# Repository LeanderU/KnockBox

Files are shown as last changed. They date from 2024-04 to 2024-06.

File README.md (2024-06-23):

# KnockBox

Want to stay in contact with your friends, family, or partner over long distances? The KnockBox was created to foster a sense of proximity to them. Instead of physically knocking on their door, you can knock on your box, and theirs will imitate your physical knocking. Additionally, the pair of identical boxes can exchange short audio messages, similar to Walkie Talkies.  

## How it works:

This project focuses on an interactive device that communicates with identical boxes, independent of their locations. The boxes are connected via the Internet, allowing them to exchange knocking sounds and audio messages. A servo imitates the physical knocking coming from a user of another box, while an LED indicates if a new audio message has been received. The user interface is limited to only one button that's used for playing the received audio message, recording a message, and sending it.

## Repository Contents:

1. **Docs**: Contains the Product Brief and Project Requirements.
2. **Electrical**: Includes schematics and PCB design files.
3. **Software**: Contains testing of submodules.

*Please note that the code of the final KnockBox and documentation on the hardware development are still under revision and have not yet been included in this repository.*

https://github.com/LeanderU/KnockBox/assets/84909019/8b67ddaa-3543-461e-bd95-6ebf5e21cfc9

The video shown only demonstrates the ability to record and play the knocking sound. The capability of recording and replaying audio messages is not implemented yet.

KnockBox_Iso
KnockBox_Front
PXL_20240531_070939251 MP
Overview_with_descriptions

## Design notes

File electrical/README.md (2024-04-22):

After Assembly:

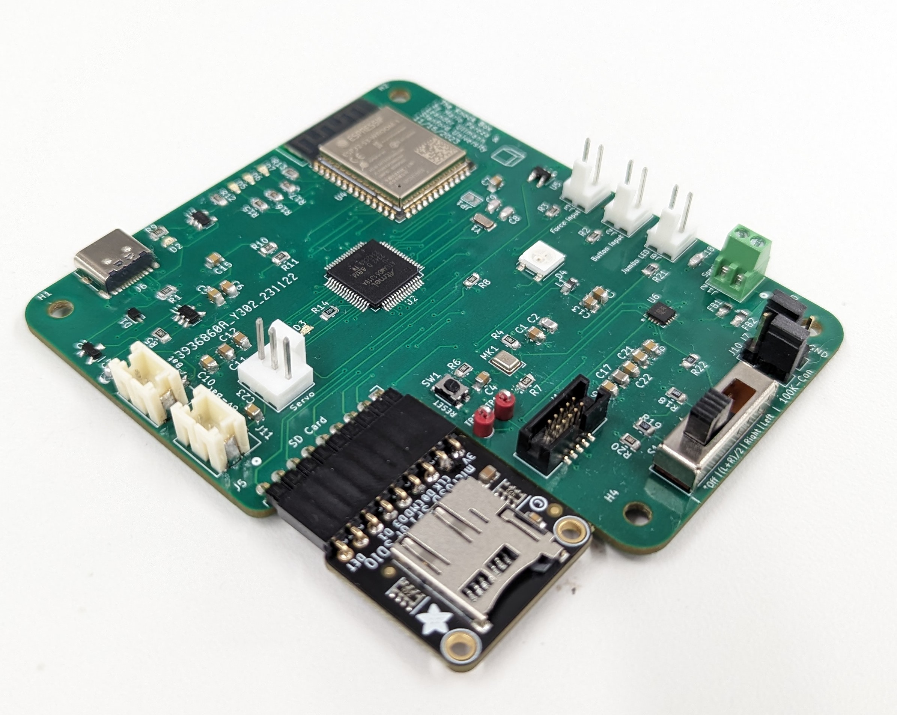
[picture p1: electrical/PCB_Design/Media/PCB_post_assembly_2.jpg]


Screenshot from KiCad before the files were sent to the Manufacturer:

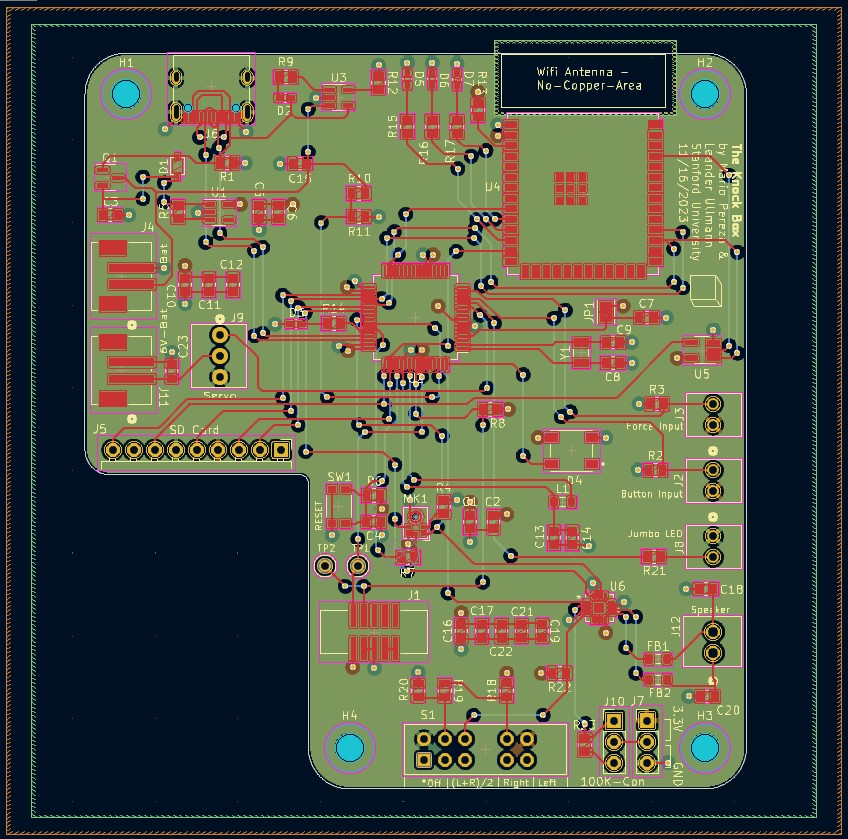
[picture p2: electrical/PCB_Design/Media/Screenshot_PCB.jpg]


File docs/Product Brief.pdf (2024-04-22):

Key features:
- Force sensor detects knocking on the box
- Servo imitates the knocking in the other box instantaneously
- Microphone used for short audio clips that are sent to second box
- Wifi modules enables communication via internet
- LED to signal a received audio clip
- Button to request to play the clip
- Speaker to output the audio clip received

Product Brief: Knock Box

Description

A way to feel more connected to those you care for by giving them a physical representation of your love. A pair of identical boxes communicating to each other. Both boxes send and receive knocks as well as audio messages.

Introduction
Want to stay in contact with your friends, family or partner over long distance?
Send a voice message and simply knock on their door…well…box to remind them that you’re there for them.
Of course, it also works the other way around, so wait until you hear a knocking sound or see the LED to indicate that you have received a new message.

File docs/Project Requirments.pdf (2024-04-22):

# Knock Box Requirements

The Knock Box comes in pairs. There must be two connected boxes for them to properly function. These boxes provide a way to feel more connected to those you care for by giving them a physical representation of your love.

# General Requirements

1. The Knock box shall be of cuboid shape
2. The walls of the cuboid shall be made out of a wooden material
3. Shall be able to record and send audio
4. An incoming message shall be signaled by an LED which turns off after the received audio message has been played
5. A speaker (power supply < 12V) shall play the received audio message when a button has been pressed

# User Interfaces

Audio Recording
- There shall be a button to hold when the user wants to record an audio message.
- A microphone shall record a voice message for up to 10 seconds.

Haptics
- The user will be able to knock on their box to trigger a simulated knock on the corresponding paired box.
- The knocking shall be detected by a force sensor
- The knocking sound on the corresponding box shall be accomplished by a hammer-like object that is attached to a servo motor.

# Communications

### WiFi

1. The Knock Box shall be capable of functioning as a WiFi client on 802.11 b/g/n wireless networks to communicate with another Knock Box

# Power

1. The Knock Box shall be powered by an internal rechargeable battery.
2. The Knock Box shall be able to be mains powered via an AC power adapter.

3. The AC power adapter shall be capable of providing power using mains voltages from 100 VAC to 240 VAC ± 10% with line frequencies of 50 to 60 Hz.
4. The Knock Box shall be able to run for over 8 hours when powered from its fully charged internal Li-Ion batteries.
5. The internal Li-Ion battery shall be able to be charged via the USB port.
6. The internal Li-Ion battery shall be able to be charged via the AC power adapter port.

# Environmental

1. Ingress protection for the Kock Box shall be IP 41 per ANSI/IEC 60529
2. The Knock Box shall operate over a temperature range of 0 °C to +40 °C with the internal Li-Ion battery installed.
3. The Knock Box shall operate over a temperature range of 0 °C to +50 °C without the internal Li-Ion battery installed.
4. The Knock Box shall sustain no damage while stored or placed in a non-operating condition over a temperature range of -20 °C to +60 °C with no internal Li-Ion battery installed.
5. The Knock Box shall be operable under the following temperature / humidity conditions:
a. 10 °C to 30 °C - up to 95% relative humidity, non-condensing
b. 30 °C to 40 °C - up to 75% relative humidity, non-condensing
c. 40 °C to 50 °C - up to 45% relative humidity, non-condensing
6. Under non-operating conditions, the Knock Box shall sustain no damage from 0 % to 98% relative humidity, non-condensing over the temperature range from -20 °C to +60 °C.
7. The Knock Box shall be operable from 400 m below mean sea level to 3,000 m above mean sea level.
8. A non-operational Knock Box shall sustain no damage from exposure to altitudes from 500 m below mean sea level to 12,000 m above mean sea level regardless of exposure duration.
9. The Knock Box shall be capable of operating under conditions of sinusoidal vibration of 3 g maximum according to MIL-PRF-28800F, Class 2.
10. The Knock Box shall be capable of operating under conditions of 30 g shock according to MIL-PRF-28800F, Class 2.
11. The Knock Box shall suffer no damage when dropped from a height of 10 cm per MIL-STD-810H

# Regulatory

1. The Knock Box shall meet or exceed the requirements of electromagnetic compatibility standards EN IEC 61326-1:2021 and EN IEC 61326-2:2021 for emission and immunity.

2. The Knock Box shall meet or exceed the requirements of UL61010-1:2023, CAN/CSA C22.2 No. 61010.1-12, EN 61010-1:2010.
3. The Knock Box shall meet or exceed the requirements of IEC / EN 61000-4-2 testing.

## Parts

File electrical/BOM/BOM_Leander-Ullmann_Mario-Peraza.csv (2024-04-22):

BOM - Knock Box
Note: Quantities in red refer to two boxes (one for Mario and one for Leander) plus some reasonable buffer.
# | Sourced | Placed | References | Value | Footprint | MFR | MFR Part Number | Supplier 1 | Supplier 1 Part Number | URL | $ per Unit | Quantity single Box | $ per categorie per box | Quantity to Order (two Boxes plus buffer) | $ per categorie for both boxes plus buffer
1 |  |  | C3, C5, C10, C15, C16, C19, C21, C22, C23 | 10uF | G-21_MUR | Murata Electronics | GRM21BR61C106KE15K | DigiKey | 490-6473-1-ND |  | $0.18 | 9 | $1.62 | 22 | $3.96
2 |  |  | C1, C4, C6, C7, C11, C12, C13, C14 | 1uF | G-21_MUR | Murata Electronics | GRM21BR71C105KA01L | DigiKey | 490-1691-1-ND |  | $0.21 | 8 | $1.68 | 20 | $4.20
3 |  |  | C2, C18, C20 | 220pF | G-21_MUR | Murata Electronics | GRM21A5C2E221JW01D | DigiKey | 490-13371-1-ND |  | $0.25 | 3 | $0.75 | 10 | $2.50
4 |  |  | C8, C9 | 22pF | G-21_MUR | Murata Electronics | GRM21A5C2D220JW01D | DigiKey | 490-14650-1-ND |  | $0.25 | 2 | $0.50 | 8 | $2.00
5 |  |  | C17 | 0.1uF | G-21_MUR | Murata Electronics | GRM21B7U1A104JA01L | DigiKey | 490-11592-1-ND |  | $0.32 | 1 | $0.32 | 6 | $1.92
6 |  |  | R2, R3, R4, R5, R6, R8, R12, R13 | 10K | STA_RMCF0805_STP | Stackpole Electronics Inc | RMCF0805FT10K0 | DigiKey | RMCF0805FT10K0CT-ND |  | $0.10 | 8 | $0.80 | 20 | $2.00
7 |  |  | R9, R15, R16, R17, R20 | 1K | STA_RMCF0805_STP | Stackpole Electronics Inc | RMCF0805FT1K00 | DigiKey | RMCF0805FT1K00CT-ND |  | $0.10 | 5 | $0.50 | 14 | $1.40
8 |  |  | R1, R10, R11, R23 | 100K | STA_RMCF0805_STP | Stackpole Electronics Inc | RMCF0805FT100K | DigiKey | RMCF0805FT100KCT-ND |  | $0.10 | 4 | $0.40 | 12 | $1.20
9 |  |  | R14, R19, R21 | 2.2K | STA_RMCF0805_STP | Stackpole Electronics Inc | RMCF0805FT2K20 | DigiKey | RMCF0805FT2K20CT-ND |  | $0.10 | 3 | $0.30 | 10 | $1.00
10 |  |  | R7 | 68 | STA_RMCF0805_STP | Stackpole Electronics Inc | RMCF0805JT68R0 | DigiKey | RMCF0805JT68R0CT-ND |  | $0.10 | 1 | $0.10 | 4 | $0.40
11 |  |  | R18 | 6.8K | STA_RMCF0805_STP | Stackpole Electronics Inc | RMCF0805FT6K80 | DigiKey | RMCF0805FT6K80CT-ND |  | $0.10 | 1 | $0.10 | 4 | $0.40
12 |  |  | R22 | 1M | STA_RMCF0805_STP | Stackpole Electronics Inc | RMCF0805JT1M00 | DigiKey | RMCF0805JT1M00CT-ND |  | $0.10 | 1 | $0.10 | 4 | $0.40
13 |  |  | L1 | 10uH | L_0805_2012Metric | Bourns Inc. | CV201210-100K | DigiKey | CV201210-100KCT-ND |  | $0.10 | 1 | $0.10 | 4 | $0.40
14 |  |  | D3, D6 | RED LED | LED_LTST-C191KRKT_LTO | Lite-On Inc. | LTST-C191KRKT | DigiKey | 160-1447-1-ND |  | $0.25 | 2 | $0.50 | 6 | $1.50
15 |  |  | D1 | D_Schottky | SDO_RB550VM-30TE-17_ROM | Rohm Semiconductor | RB550VM-30TE-17 | DigiKey | 846-RB550VM-30TE-17CT-ND |  | $0.38 | 1 | $0.38 | 4 | $1.52
16 |  |  | D2 | ORANGE LED | LED_LTST-C191KRKT_LTO | Lite-On Inc. | LTST-C191KFKT | DigiKey | 160-1445-1-ND |  | $0.23 | 1 | $0.23 | 4 | $0.92
17 |  |  | D4 | NeoPixel_THT | LED_1655 | Adafruit Industries LLC | 1655 | DigiKey | 1528-1104-ND |  | $4.50 | 1 | $4.50 | 4 | $18.00
18 |  |  | D5 | BLUE LED | LED_LTST-C191KRKT_LTO | Lite-On Inc. | LTST-C191TBKT | DigiKey | 160-1647-1-ND |  | $0.34 | 1 | $0.34 | 4 | $1.36
19 |  |  | D7 | GREEN LED | LED_LTST-C191KRKT_LTO | Lite-On Inc. | LTST-C191KGKT | DigiKey | 160-1446-1-ND |  | $0.25 | 1 | $0.25 | 4 | $1.00
20 |  |  | U1 | AP2112K-3.3 | SOT-23-5 | Diodes Incorporated | AP2112K-3.3TRG1 | DigiKey | AP2112K-3.3TRG1DICT-ND |  | $0.35 | 1 | $0.35 | 3 | $1.05
21 |  |  | U2 | ATSAMD51J19A-A | TQFP-64_10x10mm_P0.5mm | Microchip Technology | ATSAMD51J19A-AUT | DigiKey | ATSAMD51J19A-AUTCT-ND |  | $5.68 | 1 | $5.68 | 3 | $17.04
22 |  |  | U3 | MCP73831-2-OT | SOT-23-5 | Microchip Technology | MCP73831T-2ACI/OT | DigiKey | MCP73831T-2ACI/OTCT-ND |  | $0.76 | 1 | $0.76 | 3 | $2.28
23 |  |  | U4 | ESP32-S3-WROOM-1-N16R8 | ESP32-S3-WROOM-1U_EXP | Espressif Systems | ESP32-S3-WROOM-1-N16R8 | DigiKey | 1965-ESP32-S3-WROOM-1-N16R8CT-ND |  | $2.95 | 1 | $2.95 | 3 | $8.85
24 |  |  | U5 | 74AHC1G125 | USB_C_Receptacle_XKB_U262-16XN-4BVC11 | Texas Instruments | SN74AHC1G125DBVR | DigiKey | 296-8744-1-ND |  | $0.37 | 1 | $0.37 | 3 | $1.11
25 |  |  | U6 | MAX98357AETE+T | 21-0136I_T1633-4_MXM | Analog Devices Inc./Maxim Integrated | MAX98357AETE+T | DigiKey | MAX98357AETE+TCT-ND |  | $2.89 | 1 | $2.89 | 3 | $8.67
26 |  |  | Y1 | Crystal | Crystal_SMD_MicroCrystal_CC7V-T1A-2Pin_3.2x1.5mm | ECS Inc. | ECS-.327-12.5-34B-TR | DigiKey | XC1617CT-ND |  | $0.44 | 1 | $0.44 | 4 | $1.76
27 |  |  | SW1 | KMR231NG LFS | IC4_KMR231NGLFS_CNK |  | KMR231NG LFS | DigiKey | CKN10246CT-ND |  | $0.64 | 1 | $0.64 | 4 | $2.56
28 |  |  | H1, H2, H3, H4 | MountingHole | MountingHole_3.2mm_M3_ISO7380 |  |  |  |  |  |  | 4 | $- | 0 | $-
29 |  |  | FB1, FB2 | FerriteBead | L_0805_2012Metric | Laird-Signal Integrity Products | HI0805Q310R-10 | DigiKey | 240-2394-1-ND |  | $0.20 | 2 | $0.40 | 6 | $1.20
30 |  |  | TP1, TP2 | TestPoint | KEYSTONE_5000 | Keystone Electronics | 5000 | DigiKey | 36-5000-ND |  | $0.38 | 2 | $0.76 | 6 | $2.28
31 |  |  | JP1 | ~ | SolderJumper-2_P1.3mm_Open_TrianglePad1.0x1.5mm |  |  |  |  |  |  | 1 | $- | 0 | $-
32 |  |  | MK1 | SPH0645LM4H | Knowles_SPH0645LM4H-6_3.5x2.65mm | Knowles | SPH0645LM4H-B | DigiKey | 423-SPH0645LM4H-BCT-ND |  | $2.74 | 1 | $2.74 | 4 | $10.96
33 |  |  | Q1 | BSS84 | SOT-23 | Diodes Incorporated | BSS84-7-F | DigiKey | BSS84-FDICT-ND |  | $0.24 | 1 | $0.24 | 3 | $0.72
34 |  |  | S1 | SS-24E06-TG_5__P_ | SW_SS-24E06-TG_5__P_ | C&K | SS-24E06-TG 5 (P) | DigiKey | CKN10394-ND |  | $1.15 | 1 | $1.15 | 3 | $3.45
35 |  |  | J2, J3, J8 | Molex2 | CONN_22232021_MOL | Molex | 22232021 | DigiKey | 900-0022232021-ND |  | $0.21 | 3 | $0.63 | 8 | $1.68
36 |  |  | J4, J11 | B2B-PH-SM4-TB | CONN_B2B-PH-SM4-TBLFSN_JST | JST Sales America Inc. | B2B-PH-SM4-TB | DigiKey | 455-B2B-PH-SM4-TBCT-ND |  | $0.55 | 2 | $1.10 | 6 | $3.30
37 |  |  | J7, J10 | 61300311121 | PinHeader_1x03_P2.54mm_Vertical | Würth Elektronik | 61300311121 | DigiKey | 732-5316-ND |  | $0.13 | 2 | $0.26 | 6 | $0.78
38 |  |  | J1 | 3221-10-0300-00 | CONN10_3221-10-0300-00_CNC | CNC Tech | 3221-10-0300-00 | DigiKey | 1175-1735-ND |  | $0.76 | 1 | $0.76 | 3 | $2.28
39 |  |  | J5 | 61300911021 | PinHeader_1x09_P2.54mm_Horizontal | Würth Elektronik | 61300911021 | DigiKey | 732-5342-ND |  | $0.88 | 1 | $0.88 | 3 | $2.64
40 |  |  | J6 | USB_C_Receptacle_USB2.0 | USB_C_Receptacle_XKB_U262-16XN-4BVC11 | XKB Connectivity | U262-161N-4BVC11 | LCSC ELECTRONICS | C319148 |  | $0.40 | 1 | $0.40 | 3 | $1.20
41 |  |  | J9 | Molex3 | CONN3_22232031_MOL | Molex | 22232031 | DigiKey | WM4201-ND |  | $0.27 | 1 | $0.27 | 3 | $0.81
42 |  |  | J12 | OSTVN02A150 | CONN_OSTVN02A150_OST | On Shore Technology Inc. | OSTVN02A150 | DigiKey | ED10561-ND |  | $1.08 | 1 | $1.08 | 3 | $3.24
43 |  |  | not part of PCB | Force Sensor |  | Adafruit Industries LLC | 1075 | Adafruit Industries LLC | 1075 |  | $5.95 | 1 | $5.95 | 2 | $11.90
44 |  |  | not part of PCB | Jumbo LED Green |  | Kingbright | WP813GD | DigiKey | 754-1898-ND |  | $0.43 | 1 | $0.43 | 2 | $0.86
45 |  |  | not part of PCB | Jumbo LED Red |  | Kingbright | WP813SURDK | DigiKey | 754-WP813SURDK-ND |  | $0.62 | 0 | $- | 2 | $1.24
46 |  |  | not part of PCB | 6V Servo Motor |  | Parallax Inc. | 900-00005 | DigiKey | 900-00005-ND |  | $15.87 | 1 | $15.87 | 2 | $31.74
47 |  |  | not part of PCB | 16mm Flush Button |  | - | - | Ebay | 1.31657E+11 | https://www.ebay.com/itm/131657180740 | $5.99 | 1 | $5.99 | 2 | $11.98
48 |  |  | not part of PCB | SD-Card-Module |  | Adafruit Industries LLC | 4682 | DigiKey | 1528-4682-ND |  | $3.50 | 1 | $3.50 | 3 | $10.50
49 |  |  | not part of PCB | Jumper Pin Shunts |  | Sullins Connector Solutions | STC02SYAN | DigiKey | S9000-ND |  | $0.10 | 2 | $0.20 | 6 | $0.60
50 |  |  | not part of PCB | Female Socket Angled |  | Sullins Connector Solutions | PPPC091LGBN-RC | DigiKey | S5484-ND |  | $0.77 | 1 | $0.77 | 2 | $1.54
51 |  |  | not part of PCB | Male Header Angled |  | W�rth Elektronik | 61300911021 | DigiKey | 732-5342-ND |  | $0.88 | 1 | $0.88 | 2 | $1.76
52 |  |  | not part of PCB | Molex Crimp Housing 2 Pins |  | Molex | 22013027 | DigiKey | 900-0022013027-ND |  | $0.16 | 3 | $0.48 | 10 | $1.60
53 |  |  | not part of PCB | Molex Crimp Housing 3 Pins |  | Molex | 22013037 | DigiKey | 900-0022013037-ND |  | $0.19 | 1 | $0.19 | 3 | $0.57
54 |  |  | not part of PCB | Crimp Terminals |  | Molex | 8650804 | DigiKey | WM2756CT-ND |  | $0.10 | 9 | $0.90 | 30 | $3.00
55 |  |  | not part of PCB | Battery Pack |  | Adafruit Industries LLC | 3859 | DigiKey | 1528-2707-ND |  | $2.95 | 1 | $2.95 | 2 | $5.90
56 |  |  | not part of PCB | AA Batteries |  | Panasonic - BSG | LR6XWA/BXU | DigiKey | 11-LR6XWA/BXU-ND |  | $0.44 | 4 | $1.76 | 8 | $3.52
57 |  |  | not part of PCB | Lithion Battery 3.7V |  | SparkFun Electronics | PRT-13855 | DigiKey | 1568-1686-ND |  | $13.95 | 1 | $13.95 | 2 | $27.90
 |  |  |  | SD Card |  |  |  |  |  |  |  |  | $92.04 |  | $238.55
 |  |  |  | Speaker

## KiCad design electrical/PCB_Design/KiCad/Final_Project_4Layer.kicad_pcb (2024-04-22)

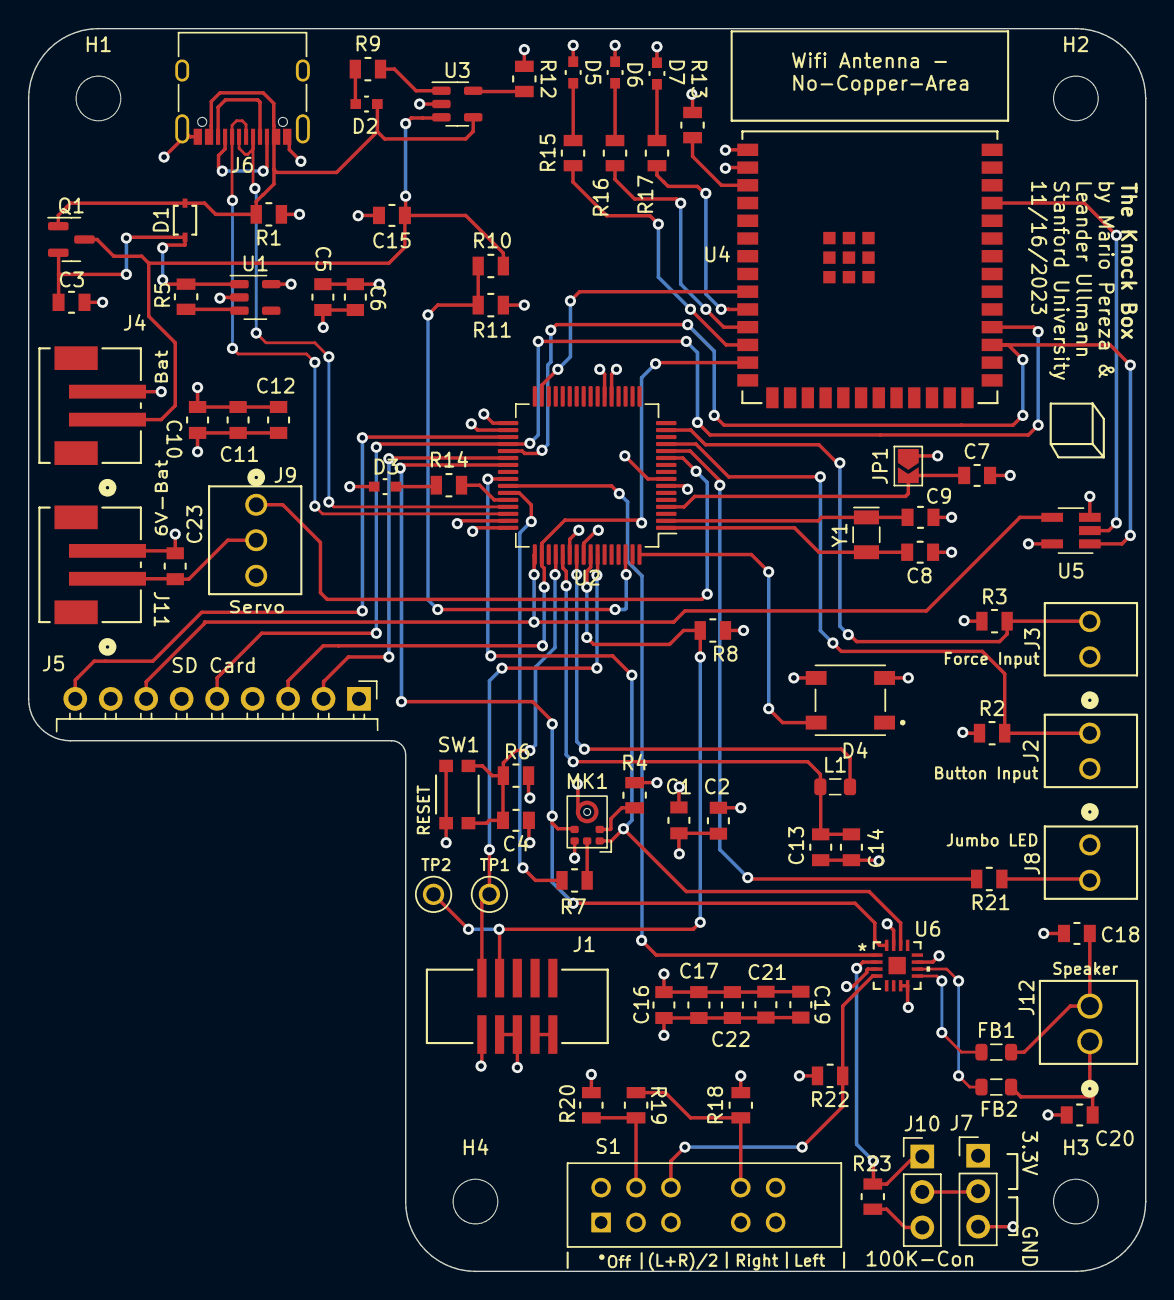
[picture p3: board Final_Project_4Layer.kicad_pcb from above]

Board: 4 copper layers, 80.0 x 89.0 mm, 86 parts (0 on the bottom side), 60 nets.

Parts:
C1, C4, C6, C7, C11, C12, C13, C14: 1uF; G-21_MUR
C2, C18, C20: 220pF; G-21_MUR
C3, C5, C10, C15, C16, C19, C21, C22, C23: 10uF; G-21_MUR
C8, C9: 22pF; G-21_MUR
C17: 0.1uF; G-21_MUR
D1: D_Schottky; SDO_RB550VM-30TE-17_ROM
D2: ORANGE LED; LED_LTST-C191KRKT_LTO
D3, D6: RED LED; LED_LTST-C191KRKT_LTO
D4: NeoPixel_THT; LED_1655
D5: BLUE LED; LED_LTST-C191KRKT_LTO
D7: GREEN LED; LED_LTST-C191KRKT_LTO
FB1, FB2: FerriteBead; L_0805_2012Metric
H1, H2, H3, H4: MountingHole; MountingHole_3.2mm_M3_ISO7380
J1: 3221-10-0300-00; CONN10_3221-10-0300-00_CNC
J2, J3, J8: Molex2; CONN_22232021_MOL
J4, J11: B2B-PH-SM4-TB; CONN_B2B-PH-SM4-TBLFSN_JST
J5: 61300911021; PinHeader_1x09_P2.54mm_Horizontal
J6: USB_C_Receptacle_USB2.0; USB_C_Receptacle_XKB_U262-16XN-4BVC11
J7, J10: 61300311121; PinHeader_1x03_P2.54mm_Vertical
J9: Molex3; CONN3_22232031_MOL
J12: OSTVN02A150; CONN_OSTVN02A150_OST
JP1: SolderJumper-2_P1.3mm_Open_TrianglePad1.0x1.5mm
L1: 10uH; L_0805_2012Metric
MK1: SPH0645LM4H; Knowles_SPH0645LM4H-6_3.5x2.65mm
Q1: BSS84; SOT-23
R1, R10, R11, R23: 100K; STA_RMCF0805_STP
R2, R3, R4, R5, R6, R8, R12, R13: 10K; STA_RMCF0805_STP
R7: 68; STA_RMCF0805_STP
R9, R15, R16, R17, R20: 1K; STA_RMCF0805_STP
R14, R19, R21: 2.2K; STA_RMCF0805_STP
R18: 6.8K; STA_RMCF0805_STP
R22: 1M; STA_RMCF0805_STP
S1: SS-24E06-TG_5__P_; SW_SS-24E06-TG_5__P_
SW1: KMR231NG LFS; IC4_KMR231NGLFS_CNK
TP1, TP2: TestPoint; KEYSTONE_5000
U1: AP2112K-3.3; SOT-23-5
U2: ATSAMD51J19A-A; TQFP-64_10x10mm_P0.5mm
U3: MCP73831-2-OT; SOT-23-5
U4: ESP32-S3-WROOM-1-N16R8; ESP32­S3­WROOM­1U_EXP
U5: 74AHC1G125; SOT-23-5_HandSoldering
U6: MAX98357AETE+T; 21-0136I_T1633-4_MXM
Y1: Crystal; Crystal_SMD_MicroCrystal_CC7V-T1A-2Pin_3.2x1.5mm

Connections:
+3.3V: C1.1, C2.1, C5.1, C6.1, C10.1, C11.1, C12.1, C16.2, C17.2, C19.1, C21.1, C22.1, D4.3 (VDD), J1.6, J2.1, J3.1, J5.4, J7.1, JP1.1 (A), MK1.5 (VDD), R6.2, R8.1, R13.1, R18.2, R22.2, S1.6, U1.5 (VOUT), U2.8 (VDDANA), U2.21 (VDDIOB), U2.34 (VDDIO), U2.48 (VDDIO), U2.56 (VDDIO), U4.2 (VDD), U5.5 (VCC), U6.7 (VDD), U6.8 (VDD)
+6V: C23.1, J9.2, J11.1
+BATT: C15.2, J4.1, Q1.3 (D), R10.2, U3.3 (V_{BAT})
/AMPL_GAIN_SEL: J10.1, R23.1, U6.2 (GAIN_SLOT)
/AREF: C7.1, JP1.2 (B), U2.4 (PA03)
/Button_Signal: J2.2, R2.2, U2.13 (PA04)
/CS_Card: J5.2, U2.38 (PA19)
/CS_Wifi: U2.37 (PA18), U4.29 (IO5), U5.1
/Card_Detect: J5.9, U2.35 (PA16)
/ESP_Busy: U2.31 (PA14), U4.9 (IO33)
/Force_Signal: J3.2, R3.2, U2.15 (PA06)
/I2S_BCLK: MK1.4 (BCLK), U2.39 (PB16), U6.16 (BCLK)
/I2S_DIN: U2.42 (PA21), U6.1 (DIN)
/I2S_DOUT: R7.1, U2.43 (PA22)
/I2S_LRCLK: MK1.1 (WS), U2.41 (PA20), U6.14 (LRCLK)
/MISO: J5.7, U2.49 (PB22), U5.4
/MISO_ESP: U4.37 (IO23), U5.2
/MOSI: J5.3, U2.50 (PB23), U4.13 (IO14)
/SCK: J5.5, U2.36 (PA17), U4.30 (IO18)
/SD_MODE: R22.1, S1.8, U6.4 (*SD_MODE)
/SWCLK: J1.2, R8.2, TP2.TP (1), U2.57 (PA30)
/SWDIO: J1.1, TP1.TP (1), U2.58 (PA31)
/VO+: FB2.1, U6.10 (OUTN)
/VO-: FB1.1, U6.9 (OUTP)
/V_DIV: R10.1, R11.2, U2.62 (PB01)
D8_NEOPIX: D4.4 (DIN), U2.64 (PB03)
D+: J6.A6 (D+), J6.B6 (D+), U2.46 (PA25)
D-: J6.A7 (D-), J6.B7 (D-), U2.45 (PA24)
ESP_BLUE: R15.1, U4.12 (IO27)
ESP_GREEN: R17.1, U4.10 (IO25)
ESP_RED: R16.1, U4.11 (IO26)
GND: C1.2, C2.2, C3.2, C4.2, C5.2, C6.2, C7.2, C8.1, C9.1, C10.2, C11.2, C12.2, C13.1, C14.1, C15.1, C16.1, C17.1, C18.2, C19.2, C20.2, C21.2, C22.2, C23.2, D3.1 (K), D4.2 (GND), D5.1 (K), D6.1 (K), D7.1 (K), J1.7, J1.8, J4.2, J5.6, J6.A1 (GND), J6.A12 (GND), J6.B1 (GND), J6.B12 (GND), J6.S1 (SHIELD), J7.3, J8.2, J9.3, J11.2, MK1.3 (GND), R1.1, R2.1, R3.1, R4.1, R11.1, R12.1, R20.2, S1.10, SW1.1, SW1.3, U1.2 (GND), U2.7 (GNDANA), U2.22 (GND), U2.33 (GND), U2.47 (GND), U2.54 (GND), U3.2 (V_{SS}), U4.1 (GND), U5.3 (GND), U6.3 (GND), U6.11 (GND), U6.15 (GND)
JUMBO_LED: R21.1, U2.12 (PB09)
unnamed: C18.1, FB1.2, J12.2
unnamed: C20.1, FB2.2, J12.1
unnamed: C3.1, D1.1 (K), Q1.2 (S), R5.2, U1.1 (VIN)
unnamed: D2.1 (K), R9.2
unnamed: D3.2 (A), R14.2
unnamed: D5.2 (A), R15.2
unnamed: D6.2 (A), R16.2
unnamed: D7.2 (A), R17.2
unnamed: J8.1, R21.2
unnamed: J7.2, J10.2
unnamed: J10.3, R23.2
unnamed: MK1.6 (DATA), R7.2
unnamed: MK1.2 (SEL), R4.2
unnamed: R18.1, R19.1, S1.7
unnamed: R19.2, R20.1, S1.9
unnamed: R5.1, U1.3 (EN)
unnamed: C8.2, U2.1 (PA00), Y1.2
unnamed: C9.2, U2.2 (PA01), Y1.1
unnamed: C13.2, C14.2, L1.1, U2.53 (VDDCORE)
unnamed: L1.2, U2.55 (VSW)
unnamed: R12.2, U3.5 (PROG)
unnamed: R9.1, U3.1 (STAT)
unnamed: R13.2, U4.3 (EN)
PWM_Servo: J9.1, U2.11 (PB08)
RED_LED: R14.1, U2.44 (PA23)
RESET: C4.1, R6.1, SW1.2, SW1.4, U2.52 (~RESET)
VBUS: D1.2 (A), D2.2 (A), J6.A4 (VBUS), J6.A9 (VBUS), J6.B4 (VBUS), J6.B9 (VBUS), Q1.1 (G), R1.2, U3.4 (V_{DD})

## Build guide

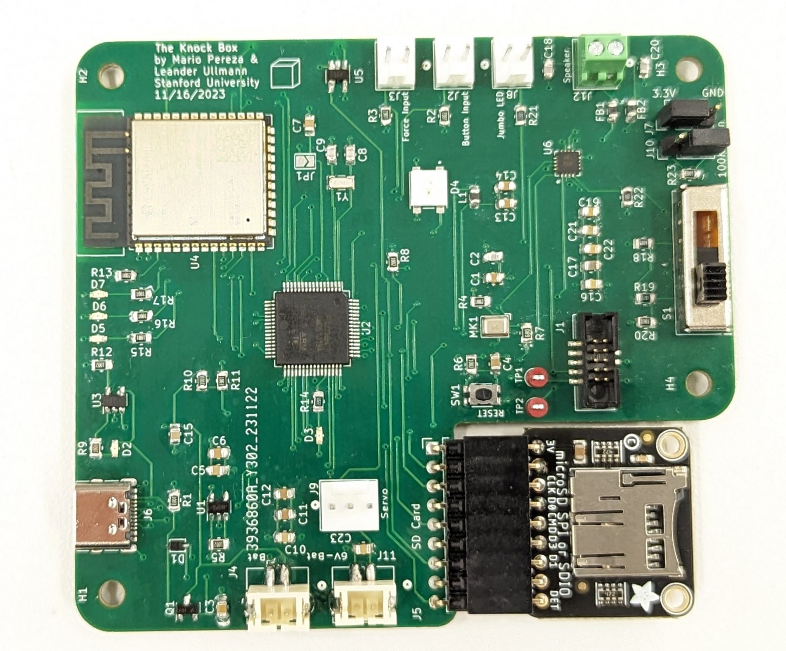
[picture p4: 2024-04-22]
electrical/PCB_Design/Media/PCB_post_assembly_1.jpg

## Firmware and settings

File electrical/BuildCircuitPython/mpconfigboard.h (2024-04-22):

#define MICROPY_HW_BOARD_NAME "Adafruit Feather M4 Express"
#define MICROPY_HW_MCU_NAME "samd51j19"

#define CIRCUITPY_MCU_FAMILY samd51

// Rev E

// #define MICROPY_HW_LED_STATUS   (&pin_PA23)
// #define MICROPY_HW_NEOPIXEL (&pin_PB03)

#define BOARD_HAS_CRYSTAL 1

// #define CIRCUITPY_DEFAULT_STACK_SIZE  (1062) // divisible by 8
// #define CIRCUITPY_INTERNAL_NVM_SIZE (8192)
#define CIRCUITPY_INTERNAL_FLASH_FILESYSTEM_SIZE (FLASH_SIZE / 2 - CIRCUITPY_INTERNAL_NVM_SIZE - CIRCUITPY_DEFAULT_STACK_SIZE)

#define DEFAULT_I2C_BUS_SCL (&pin_PA13)
#define DEFAULT_I2C_BUS_SDA (&pin_PA12)

#define DEFAULT_SPI_BUS_SCK (&pin_PA17)
#define DEFAULT_SPI_BUS_MOSI (&pin_PB23)
#define DEFAULT_SPI_BUS_MISO (&pin_PB22)

#define DEFAULT_UART_BUS_RX (&pin_PB17)
#define DEFAULT_UART_BUS_TX (&pin_PB16)

// USB is always used internally so skip the pin objects for it.
#define IGNORE_PIN_PA24     1
#define IGNORE_PIN_PA25     1

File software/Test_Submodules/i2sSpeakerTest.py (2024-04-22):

import board
import time
import audioio
# new imports for the SD card
import busio
import digitalio
import storage
import adafruit_sdcard  # add this library
from audiocore import WaveFile
import audiobusio

# The SD card uses a protocol called SPI.  We'll see much more of this very soon.
# For now, what we need is a digital line to select the SD card (cs, below), and
# connections for the SPI signal lines to the SD card (spi, below)

# Use a digital pin to select the SD card
cs = digitalio.DigitalInOut(board.PA19)
# Wire up the SPI pins
spi = audiobusio.SPI(board.PA17, board.PB23, board.PB22)

# Connect to the card and mount the filesystem.
# Once this is done, the SD card looks just like another part of the files system!
sdcard = adafruit_sdcard.SDCard(spi, cs)
vfs = storage.VfsFat(sdcard)
storage.mount(vfs, "/sd")

wave_file = open("/sd/AUDIO/example.wav", "rb") # Note the "/sd/" prefix for the SD card
wave = WaveFile(wave_file)            # Everything else is the same ...
audio = I2SOut(board.PB16, board.PA20, board.PA21)

while True:
    audio.play(wave)
    while audio.playing:
        pass

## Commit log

2024-04-22 Create BOM folder
2024-04-22 Add BOM files
    [BOM_Leander-Ullmann_Mario-Peraza.csv]
2024-04-22 Create PCB_Design folder
2024-04-22 Create KiCAD folder
